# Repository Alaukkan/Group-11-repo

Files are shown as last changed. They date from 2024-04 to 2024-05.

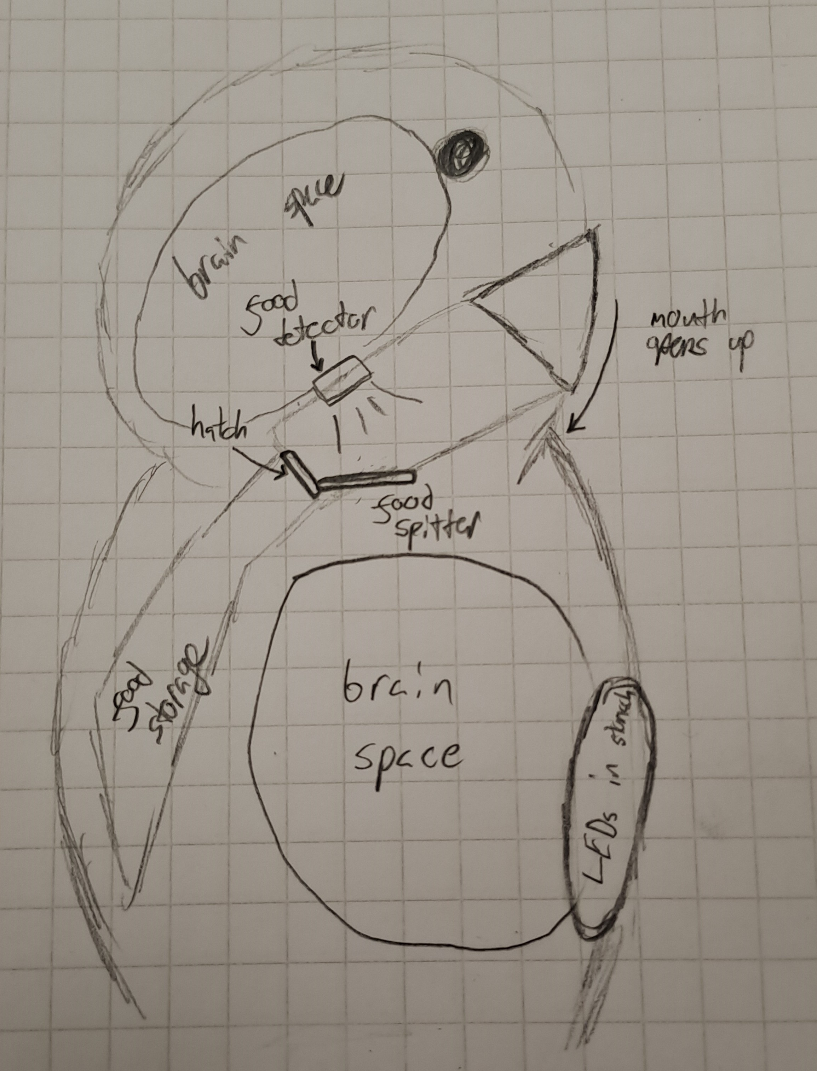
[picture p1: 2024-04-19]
Concept art/first-structure-sketch.jpg

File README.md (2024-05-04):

# Group-11 Repository

This is the repository for group-11's project in Principles of Digital Fabrication Course.

Members:
* Alex, programmer
* Anssi, prototyper
* Jouni, manager
* Petrus, designer

## Project Description

Aim of this project is to design and produce a desktop mounted robot pet resembling a penguin.
This robot pet, or RoboPet(™, Ⓒ, Patent Pending) if you will, will be stationary, but able to pivot in place and move its wings.
It is capable of simulating simple functions of a pet such as demanding particular food items and communicating using light, sound and motion.
Mechanical and structural parts needed for the project will be designed and 3D-printed by us.

## Contents of the Repository

In this repository you will find everything needed to copy and manufacture our project, including:

* Source code in main.py file.
* Additional modules, such as sound.py, servo.py, mfrc522.py, etc.
* .stl files containing design of the 3D-printed parts.
* .png and .fzz files containing schematics for electrical connections.
* .jpg and .png files containing concept art.
* Project RoboPet Documentation.md containing project description, parts list,
  software and tools used/needed, some code snippets highlighting key functionalities and information about the source code.
* README.md (this file you are reading) containing short project description,
  info about the contents of the repository and information about licenses.

## Licenses

##### The following legalese portion is not in effect yet.

Unless expressly stated otherwise all contend found in this specific repository (Alaukkan/Group-11-repo) is shared using [CC BY-SA license](https://creativecommons.org/share-your-work/cclicenses/).

More specifically above statement only relates to items used in completion of this project and those that are made by us (code or assets made by other people retain their original licenses and/or rights).

The above statements also don't extend to any other repositories made by user [Alaukkan](https://github.com/Alaukkan) or anyone else assosiated with the project or course.

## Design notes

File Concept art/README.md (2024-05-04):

# Concept art

## This folder contains images and schematics used in the project

## List of files

* alternate_first_design_of_final_concept.png
* first-structure-sketch.jpg
* initial_design_habitat.png
* main-idea.jpg

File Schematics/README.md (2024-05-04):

# Schematics

## This Folder contains .png and .fzz versions of the electronics schematics

## List of files:

* G11_Project_RoboPet_2.fzz
* G11_Project_Robopet_2.png

## Note that that Vcc for Pi Pico and Servos is provided by __Three__ (__3__) AA Batteries, not four (4)!

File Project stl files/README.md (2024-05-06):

# Project .stl files

## This folder contains .stl files that are used in the project

## List of files

* Axle_new.stl
* Battery_holder.stl
* Bottom_frame.stl
* Hat.stl
* Head.stl
* RFID_tag_42mm.stl
* Tongue.stl
* Torso.stl
* Wing.stl

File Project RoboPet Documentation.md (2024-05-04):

## Concept

Our product will be a (desktop) RoboPet (™, Ⓒ, Patent Pending), that is capable of simulating the most basic,
simple functions of a pet, namely the need for food and drink.
Product will be stationary and mounted on a rotating base, it will be able to turn left or right and move its arms
(other modes of movement might be implemented if there is time and/or resources).
Communication with the user will happen using coloured LEDs located in the torso and a buzzer located in the head.
For user interaction there will be an conveniently located on/off switch and a RFID-reader located in the mouth/head region.
RFID-reader is used to scan and recognize the different foodstuffs inserted.
A system for ingesting desired foodstuffs and discarding undesired ones will be implemented if there is time.

## Parts

* Raspberry Pi Pico W
* MFRC-522 RF-ID-Reader
* 5 RF-ID-Tags (13.56 MHz)
* 4 Servomotors (180 degree motion)
* 1 RGB LED
* Power Source (4.5V battery pack holding 3 AA batteries)
* 2 Breadboards
* Jumper Cables
* Resistors, capacitors
* 3D-Printed parts

## Tools and Software

* 3D-Printer (We used different versions of Ender-3)
* CAD Software (Fusion 360, FreeCAD, Blender with CAD Sketcher, etc.)
* Slicer Software (Cura, Slic3r, Simplify 3D, etc.)
* IDE (VS Code, Arduino IDE, Thonny, etc.)

## Functionality highlights

```Python
def read_tag():
    """
    Found library for rfid reader on github:
    https://github.com/danjperron/micropython-mfrc522
    Reads the RFID tag and returns which tag was read.
    """
    start_time = utime.time()
    reader.init()
    while utime.time() - start_time < 20:

        (stat, tag_type) = reader.request(reader.REQIDL)
        print('request stat:',stat,' tag_type:',tag_type)

        if stat == reader.OK:
            (stat, uid) = reader.SelectTagSN()
            if stat == reader.OK:
                tag_id = hex(int.from_bytes(bytes(uid),"little",False)).upper()
                print(f"{tag_to_color[tag_id]} tag detected")

                if tag_to_color[tag_id] == status["requesting_color"]:
                    return "correct"
                return "wrong"
            else:
                pass
        utime.sleep_ms(50)
    
    return "Timed out"

def output_color(color):
    """
    takes the rgb values from given parameter tuple and
    outputs the color to the RGB led
    """
    red = color[0]
    green = color[1]
    blue = color[2]
    rgb[0].duty_u16(round(65535 * red / 255))
    rgb[1].duty_u16(round(65535 * green / 255))
    rgb[2].duty_u16(round(65535 * blue / 255))

def request_food():
    """
    A random number is generated which decides what food item the Robo Pet
    wants by accessing the element in the led list. Robopet
    indicates what food it wants by a colored LED. 
    """
    random.seed(utime.time() - utime.time_ns())
    length = len(status["available"])
    if length > 1:
        item = random.randint(0, length - 1)
    else:
        item = 0
    status["requesting_color"] = status["available"][item]
    print(f"requesting food: {status["available"][item]}")
    output_color(rgb_colors[status["available"][item]])
    _thread.start_new_thread(sound.play_melody, ("requesting", 1))

def correct_food():
    """
    If the food is correct, led flashes white for 2 seconds
    both wings lift up
    hatch opens and closes
    """
    _thread.start_new_thread(sound.play_melody, ("happy", 1))
    servo_hatch.move(-60)
    servo_right_wing.move(-70)
    servo_left_wing.move(70)
    deinit_servos()
    for i in range(3):
        led_off()
        utime.sleep_ms(300)
        output_color(rgb_colors["white"])
        utime.sleep_ms(300)
    led_off()
    servo_hatch.move(0)
    servo_right_wing.move(0)
    servo_left_wing.move(0)
    deinit_servos()
    status["available"].remove(status["requesting_color"])
    status["requesting_color"] = "none"
    status["timed out"] = 0

def ending():
    if len(status["available"]) == 0:
        _thread.start_new_thread(sound.play_melody, ("victory", 1))
        for i in range(0, 255, 5):
            output_color((i, 0, 0))
            utime.sleep_ms(9)
        for i in range(0, 255, 5):
            output_color((255, i, 0))
            utime.sleep_ms(9)
        for i in range(0, 255, 5):
            output_color((255-i, 255, 0))
            utime.sleep_ms(9)
        for i in range(0, 255, 5):
            output_color((0, 255, i))
            utime.sleep_ms(9)
        for i in range(0, 255, 5):
            output_color((0, 255-i, 255))
            utime.sleep_ms(9)
        for i in range(0, 255, 5):
            output_color((i, 0, 255))
            utime.sleep_ms(9)
        for i in range(0, 255, 5):
            output_color((255, 0, 255-i))
            utime.sleep_ms(9)
    elif status["failed"] > 2:
        _thread.start_new_thread(sound.play_melody, ("defeat", 1))
        output_color(rgb_colors["red"])
        utime.sleep(1)
    elif status["timed out"] > 1:
        _thread.start_new_thread(sound.play_melody, ("power down", 1))
        for i in range(0, 255, 5):
            output_color((255, 255-i, 255-i))
            utime.sleep_ms(20)
    led_off()

```

## Source Code

Project is written and tested in [MicroPython](https://docs.micropython.org/en/latest/rp2/quickref.html) for RP2040 based
[Raspberry Pi Pico W](https://www.raspberrypi.com/documentation/microcontrollers/raspberry-pi-pico.html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),
functionality with other micro controllers is not tested.

Source Code can be found in the [GitHub repository](https://github.com/Alaukkan/Group-11-repo).

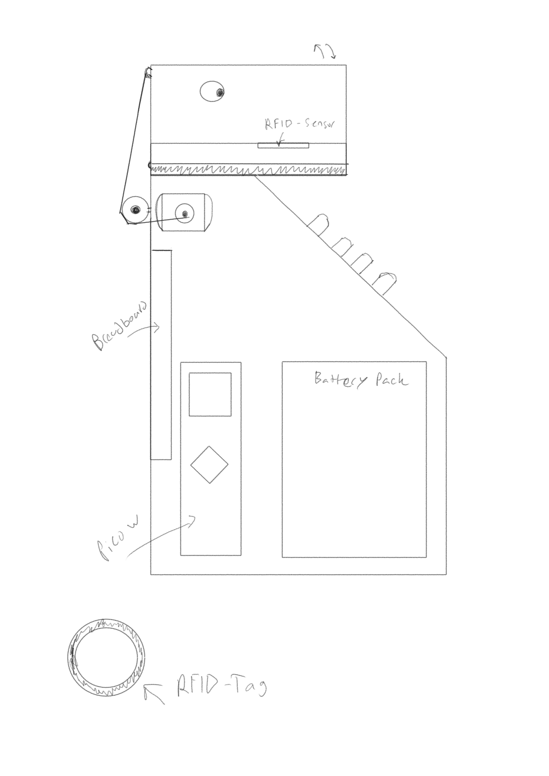
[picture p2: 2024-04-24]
Concept art/alternate_first_design_of_final_concept.png

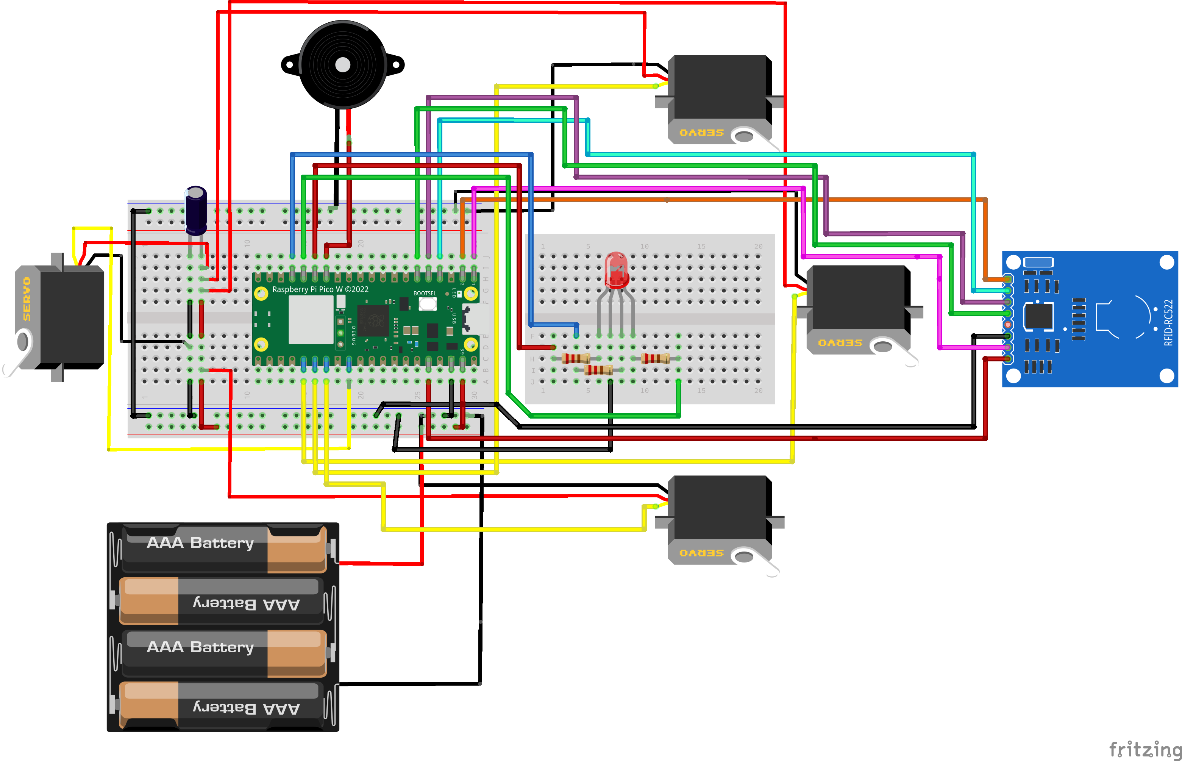
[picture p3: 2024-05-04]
Schematics/G11_Project_RoboPet_2.png

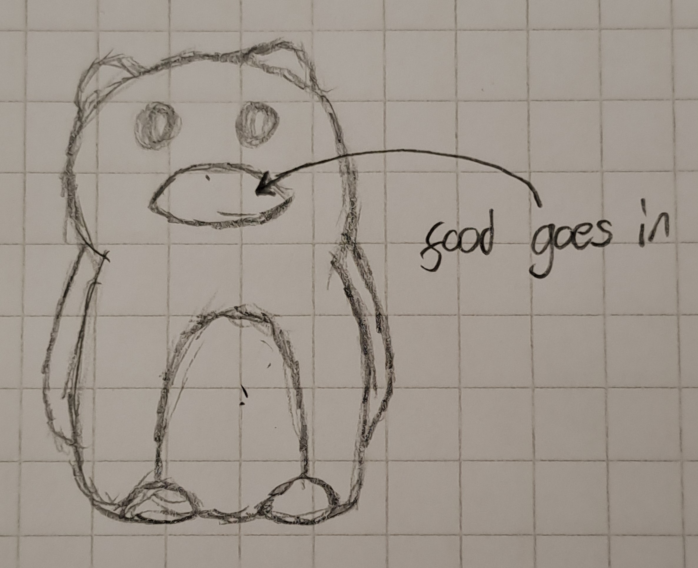
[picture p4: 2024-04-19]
Concept art/main-idea.jpg

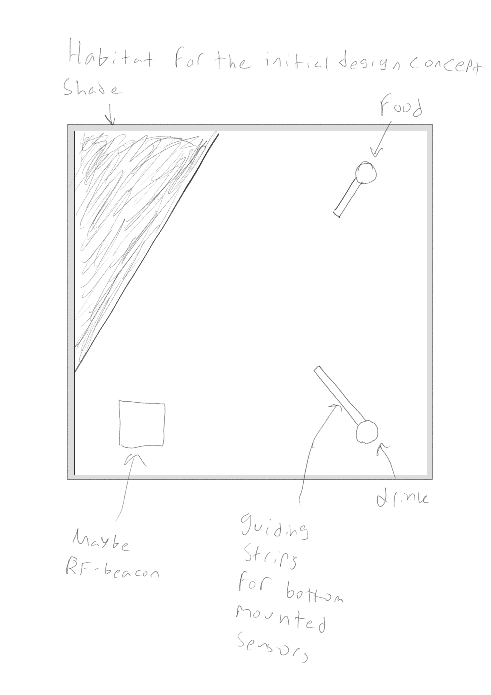
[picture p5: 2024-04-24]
Concept art/initial_design_habitat.png

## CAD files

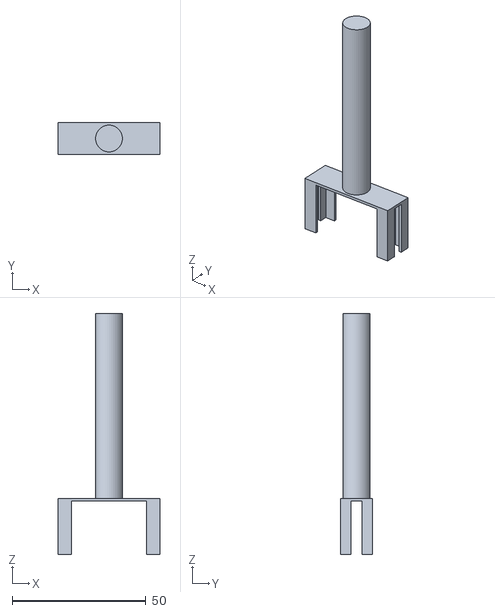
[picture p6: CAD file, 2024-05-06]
Project stl files/breadboard_holder_smaller.stl
38.0 x 12.0 x 90.0

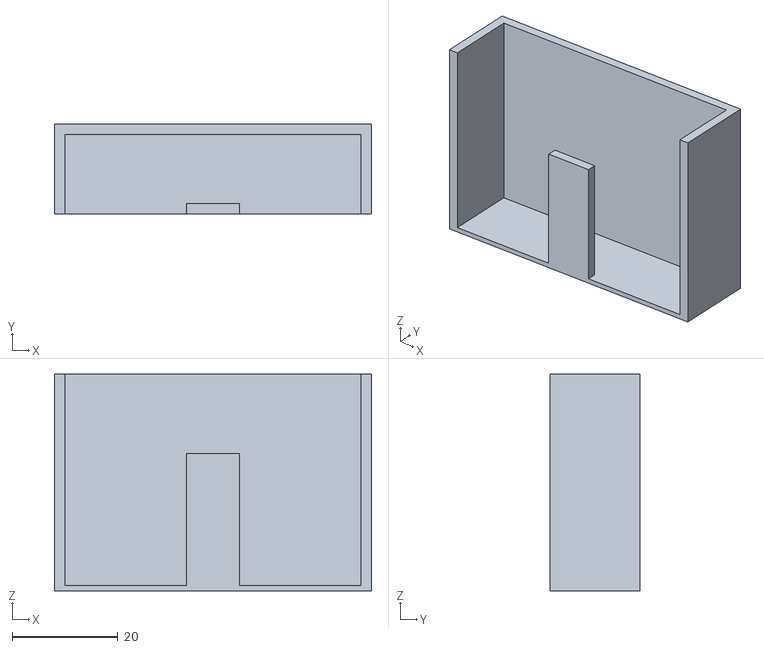
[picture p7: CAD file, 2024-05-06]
Project stl files/breadboard holder.stl
60.0 x 17.0 x 41.0

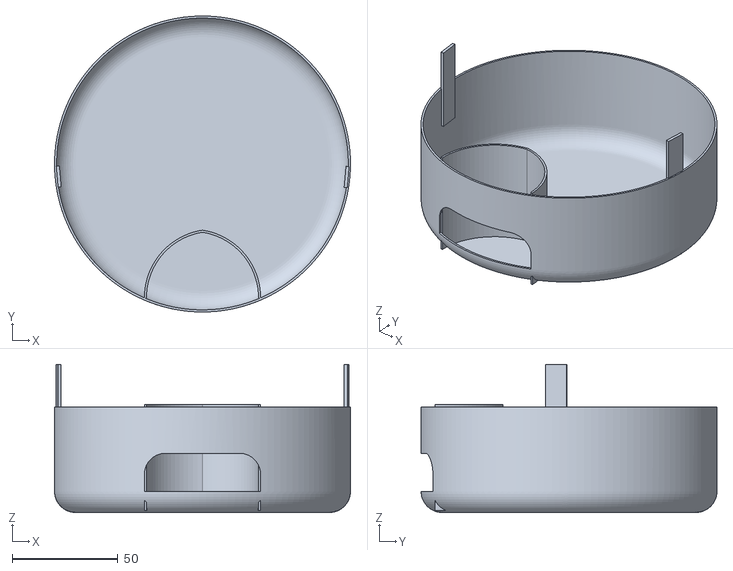
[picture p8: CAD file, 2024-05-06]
Project stl files/Bottom_of_torso.stl
140.0 x 140.0 x 70.0

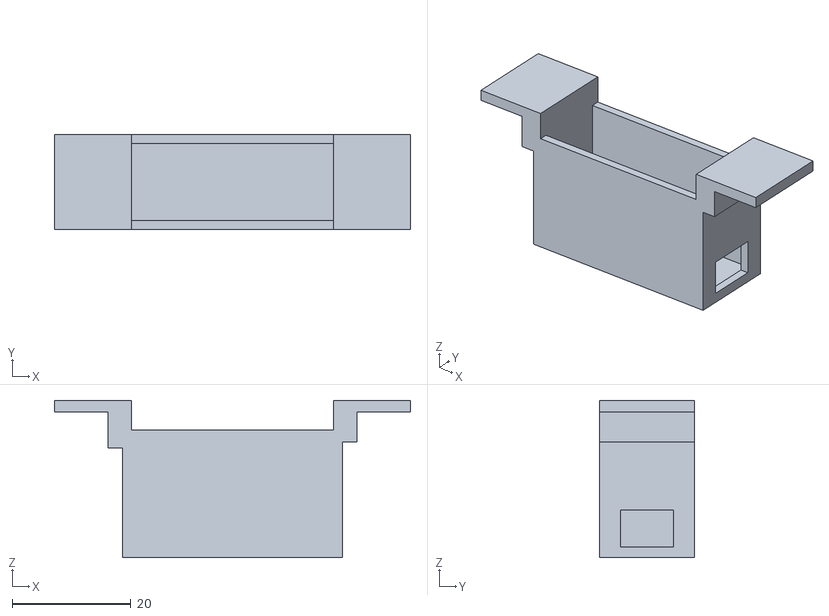
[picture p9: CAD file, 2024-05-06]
Project stl files/SERVO_HOLDER.stl
60.0 x 16.0 x 26.5

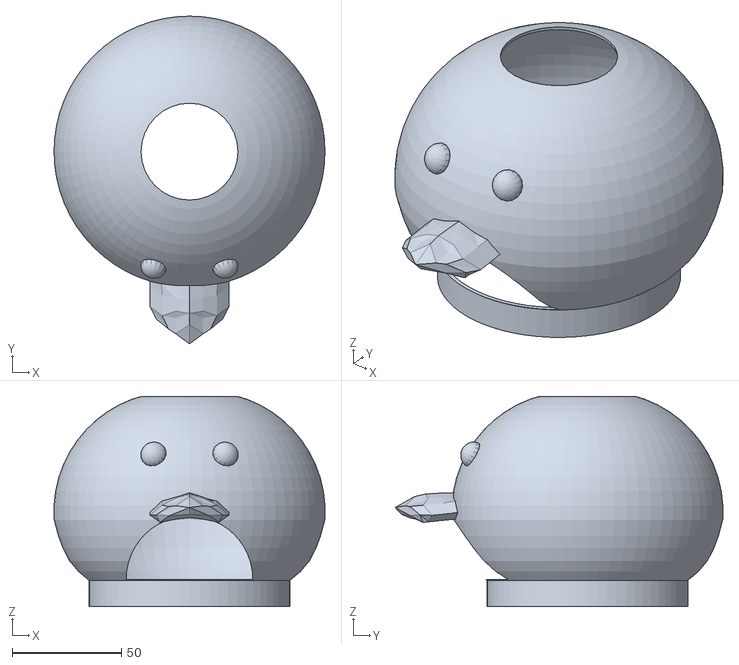
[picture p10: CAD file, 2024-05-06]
Project stl files/Head.stl
124.1 x 150.1 x 96.3

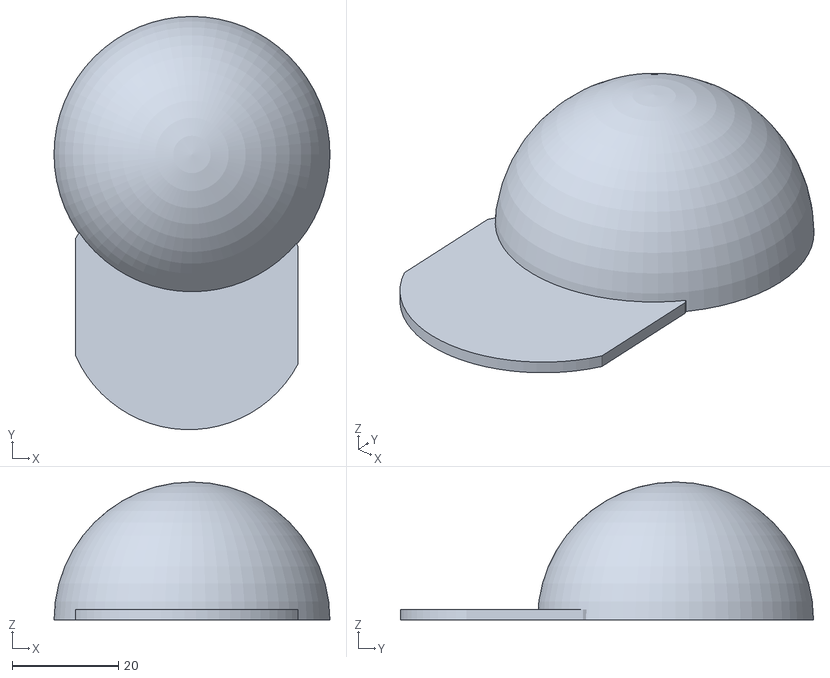
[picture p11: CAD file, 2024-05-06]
Project stl files/Hat.stl
52.0 x 77.8 x 26.0

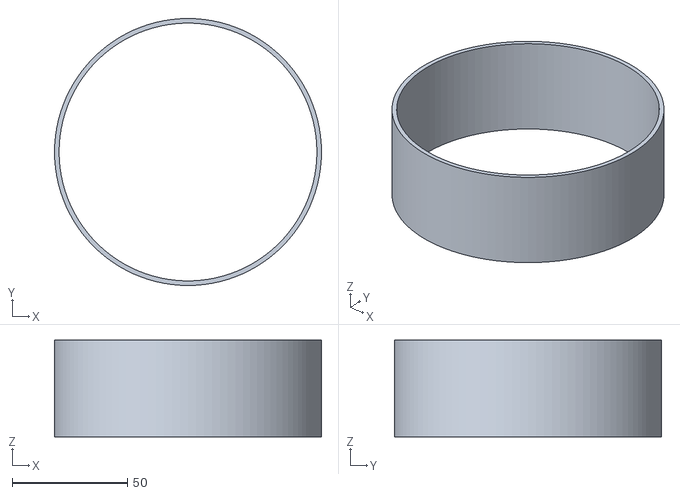
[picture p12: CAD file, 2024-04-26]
Project stl files/Bottom_frame.stl
116.0 x 116.0 x 42.0

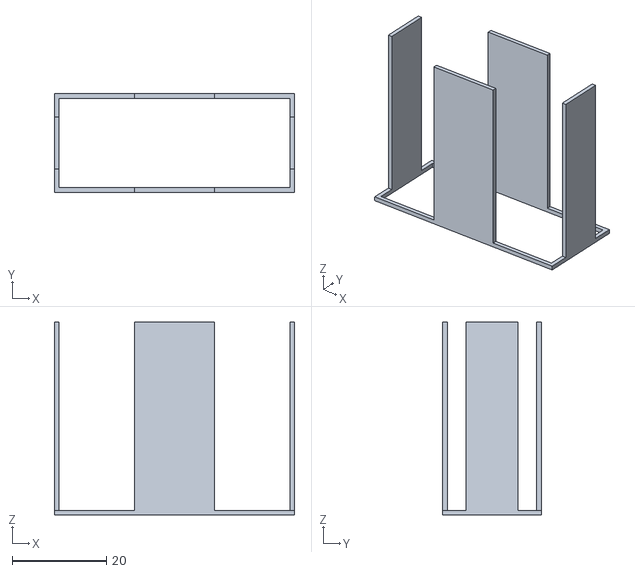
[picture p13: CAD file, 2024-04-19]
Project stl files/Battery_holder.stl
51.0 x 21.0 x 41.0

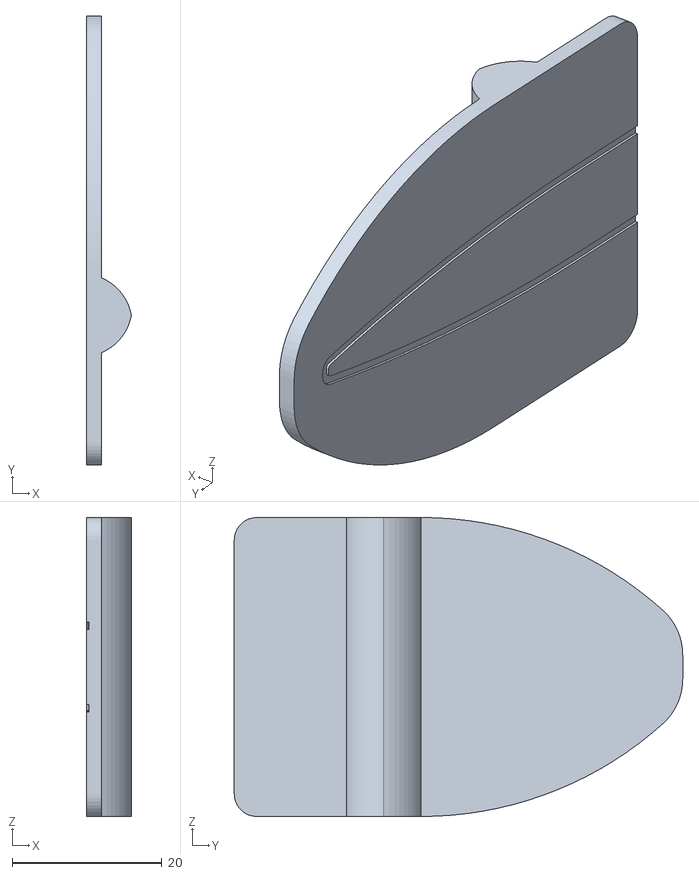
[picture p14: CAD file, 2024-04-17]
Project stl files/Tongue.stl
6.00 x 60.0 x 40.0

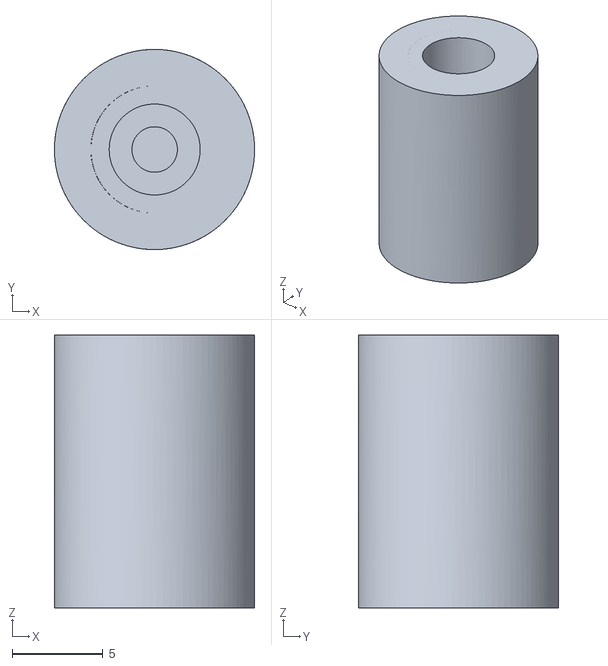
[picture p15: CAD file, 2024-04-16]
Project stl files/Axle_new.stl
11.0 x 11.0 x 15.0

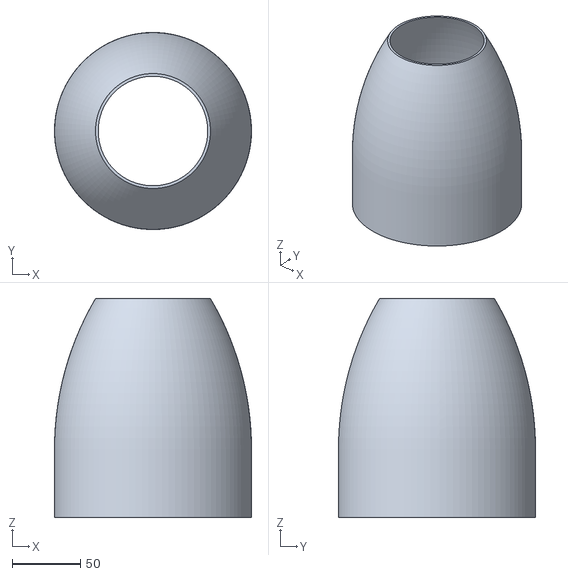
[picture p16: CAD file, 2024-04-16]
Project stl files/Torso.stl
144.0 x 144.0 x 160.0

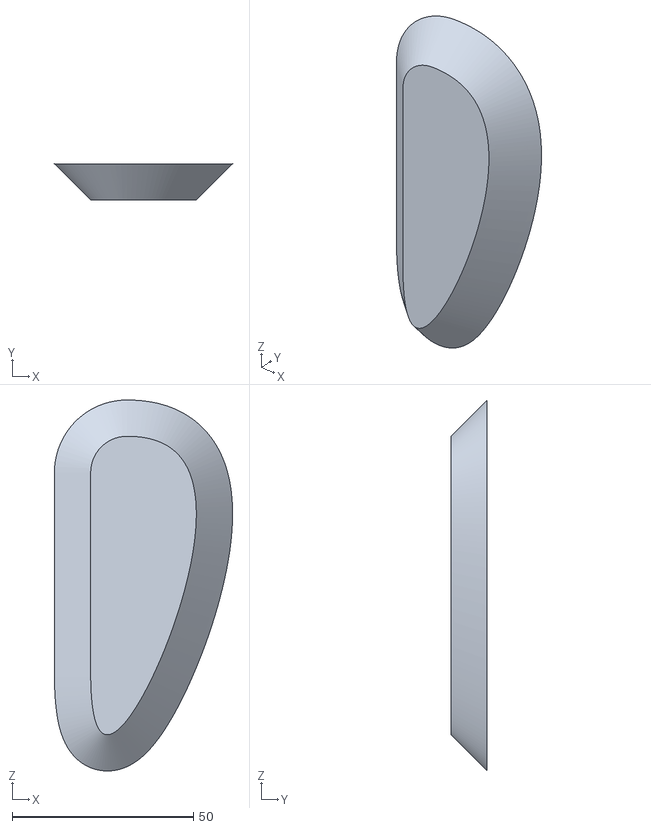
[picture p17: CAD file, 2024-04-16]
Project stl files/Wing.stl
49.1 x 10.0 x 102.3

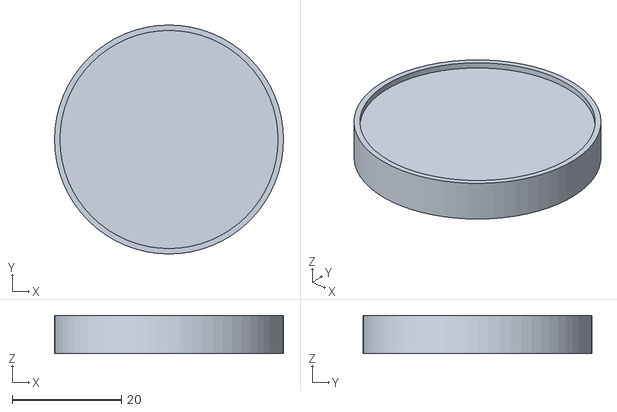
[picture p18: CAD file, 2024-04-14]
Project stl files/RFID_tag_42mm.stl
42.0 x 42.0 x 7.00

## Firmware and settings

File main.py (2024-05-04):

import random
import sound
import utime
import _thread
from machine import Pin, PWM
from mfrc522 import MFRC522
from servo import Servo

servo_hatch = Servo(19)
servo_right_wing = Servo(20)
servo_left_wing = Servo(21)
servo_rotator = Servo(22)

red_pin = PWM(Pin(11, Pin.OUT))
green_pin = PWM(Pin(12, Pin.OUT))
blue_pin = PWM(Pin(13, Pin.OUT))
red_pin.freq(1000)
green_pin.freq(1000)
blue_pin.freq(1000)

rgb = [red_pin, green_pin, blue_pin]
rgb_colors = {
    "red" : (255, 0, 0),
    "green" : (0, 255, 0),
    "blue" : (0, 0, 255),
    "yellow" : (255, 170, 0),
    "purple" : (200, 0, 255),
    "white" : (255, 255, 255)
}
                # pin numbers for RFID reader
reader = MFRC522(spi_id=0,sck=2,miso=4,mosi=3,cs=1,rst=0)
tag_to_color = {
    "0X8020B7B21B4404" : "red",
    "0X8020B7B21B6304" : "green",
    "0X8020B7B21B5504" : "blue",
    "0X8020B7B21B4304" : "yellow",
    "0X8020B7B21A8704" : "purple"
}

status = {
    "available" : ["red", "green", "blue", "yellow", "purple"],
    "requesting_color" : "none",
    "failed" : 0,
    "timed out" : 0
}

def output_color(color):
    """
    takes the rgb values from given parameter tuple and
    outputs the color to the RGB led
    """
    red = color[0]
    green = color[1]
    blue = color[2]
    rgb[0].duty_u16(round(65535 * red / 255))
    rgb[1].duty_u16(round(65535 * green / 255))
    rgb[2].duty_u16(round(65535 * blue / 255))

def led_off():
    """Turns off the RGB led"""
    rgb[0].duty_u16(0)
    rgb[1].duty_u16(0)
    rgb[2].duty_u16(0)

def deinit_servos():
    """ 
    Deinitialises servos to prevent jittering when idle
    """
    utime.sleep_ms(500)
    servo_hatch.__motor.deinit()
    servo_left_wing.__motor.deinit()
    servo_right_wing.__motor.deinit()
    servo_rotator.__motor.deinit()

def request_food():
    """
    A random number is generated which decides what food item the Robo Pet
    wants by accessing the element in the led list. Robopet
    indicates what food it wants by a colored LED. 
    """
    random.seed(utime.time() - utime.time_ns())
    length = len(status["available"])
    if length > 1:
        item = random.randint(0, length - 1)
    else:
        item = 0
    status["requesting_color"] = status["available"][item]
    print(f"requesting food: {status["available"][item]}")
    output_color(rgb_colors[status["available"][item]])
    _thread.start_new_thread(sound.play_melody, ("requesting", 1))

def read_tag():
    """
    Found library for rfid reader on github:
    https://github.com/danjperron/micropython-mfrc522
    Reads the RFID tag and returns which tag was read.
    """
    start_time = utime.time()
    reader.init()
    while utime.time() - start_time < 20:

        (stat, tag_type) = reader.request(reader.REQIDL)
        print('request stat:',stat,' tag_type:',tag_type)

        if stat == reader.OK:
            (stat, uid) = reader.SelectTagSN()
            if stat == reader.OK:
                tag_id = hex(int.from_bytes(bytes(uid),"little",False)).upper()
                print(f"{tag_to_color[tag_id]} tag detected")

                if tag_to_color[tag_id] == status["requesting_color"]:
                    return "correct"
                return "wrong"
            else:
                pass
        utime.sleep_ms(50)
    
    return "Timed out"

def correct_food():
    """
    If the food is correct, led flashes white for 2 seconds
    both wings lift up
    hatch opens and closes
    """
    _thread.start_new_thread(sound.play_melody, ("happy", 1))
    servo_hatch.move(-60)
    servo_right_wing.move(-70)
    servo_left_wing.move(70)
    deinit_servos()
    for i in range(3):
        led_off()
        utime.sleep_ms(300)
        output_color(rgb_colors["white"])
        utime.sleep_ms(300)
    led_off()
    servo_hatch.move(0)
    servo_right_wing.move(0)
    servo_left_wing.move(0)
    deinit_servos()
    status["available"].remove(status["requesting_color"])
    status["requesting_color"] = "none"
    status["timed out"] = 0

def wrong_food():
    """
    If the Robo Pet is given the wrong food, 
    the requested led will flash for 2 seconds and will stay on
    robopet rotates left and right
    wings move simultaniously opposite directions
    hatch opens "spitting" the food out and closes
    """
    _thread.start_new_thread(sound.play_melody, ("angry", 1))
    servo_hatch.move(30)
    deinit_servos()
    for i in range(3):
        led_off()
        for i in range(30):
            servo_right_wing.move(-1.5 * i)
            servo_left_wing.move(-1.5 * i)
            servo_rotator.move(i)
            utime.sleep_ms(10)
        output_color(rgb_colors[status["requesting_color"]])
        for i in range(60):
            servo_right_wing.move(-1.5 * (30 - i))
            servo_left_wing.move(-1.5 * (30 - i))
            servo_rotator.move(30 - i)
            utime.sleep_ms(10)
        for i in range(30):
            servo_right_wing.move(1.5 * (30 - i))
            servo_left_wing.move(1.5 * (30 - i))
            servo_rotator.move(i - 30)
            utime.sleep_ms(10)
    servo_right_wing.move(0)
    servo_left_wing.move(0)
    servo_hatch.move(0)
    servo_rotator.move(0)
    deinit_servos()
    status["failed"] += 1
    status["timed out"] = 0

def timed_out():
    """
    If the Robo Pet times out, the led does a long white flash
    hatch opens and closes (spits food out)
    """
    _thread.start_new_thread(sound.play_melody, ("timed out", 1))
    servo_hatch.move(30)
    deinit_servos()
    output_color(rgb_colors["white"])
    utime.sleep(2)
    led_off()
    utime.sleep(1)
    servo_hatch.move(0)
    deinit_servos()
    status["requesting_color"] = "none"
    status["timed out"] += 1

def ending():
    if len(status["available"]) == 0:
        _thread.start_new_thread(sound.play_melody, ("victory", 1))
        for i in range(0, 255, 5):
            output_color((i, 0, 0))
            utime.sleep_ms(9)
        for i in range(0, 255, 5):
            output_color((255, i, 0))
            utime.sleep_ms(9)
        for i in range(0, 255, 5):
            output_color((255-i, 255, 0))
            utime.sleep_ms(9)
        for i in range(0, 255, 5):
            output_color((0, 255, i))
            utime.sleep_ms(9)
        for i in range(0, 255, 5):
            output_color((0, 255-i, 255))
            utime.sleep_ms(9)
        for i in range(0, 255, 5):
            output_color((i, 0, 255))
            utime.sleep_ms(9)
        for i in range(0, 255, 5):
            output_color((255, 0, 255-i))
            utime.sleep_ms(9)
    elif status["failed"] > 2:
        _thread.start_new_thread(sound.play_melody, ("defeat", 1))
        output_color(rgb_colors["red"])
        utime.sleep(1)
    elif status["timed out"] > 1:
        _thread.start_new_thread(sound.play_melody, ("power down", 1))
        for i in range(0, 255, 5):
            output_color((255, 255-i, 255-i))
            utime.sleep_ms(20)
    led_off()

def timer(min, max):
    """
    Delays the excecution of the code by a random amount of time.
    min = shortest possible delay
    max = longest possible delay
    """
    delay = random.randint(min, max)
    print(f"timer: {delay}")
    utime.sleep(delay)

def check_state():
    """
    Checks the game state. Returns false if:
    - all rfid tags have been read
    - 3 wrong rfid tags have been read
    - timed out 2 times in a row
    """
    return len(status["available"]) > 0 and status["failed"] < 3 and status["timed out"] < 2

def main():
    """
    The main function of the pet. Based on the timer the pet will get hungry
    and demand food. 
    """
    deinit_servos()
    while check_state():
        timer(2, 5)
        request_food()
        while check_state():
            result = read_tag()
            if result == "wrong":
                wrong_food()
            elif result == "correct":
                correct_food()
                break
            else:
                timed_out()
                break
    ending()

main()

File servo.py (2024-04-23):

# Basic servo library found here:
# https://forums.raspberrypi.com/viewtopic.php?t=303900

from machine import Pin, PWM

class Servo:
    # these defaults work for the standard TowerPro SG90
    __servo_pwm_freq = 50
    __min_u16_duty = 1640 + 400 # offset for correction
    __max_u16_duty = 7864 - 35  # offset for correction
    min_angle = -90
    max_angle = 90    
    current_angle = 0.001
    
    
    def __init__(self, pin):
        self.__initialise(pin)
        
        
    def update_settings(self, servo_pwm_freq, min_u16_duty, max_u16_duty, min_angle, max_angle, pin):
        self.__servo_pwm_freq = servo_pwm_freq
        self.__min_u16_duty = min_u16_duty
        self.__max_u16_duty = max_u16_duty
        self.min_angle = min_angle
        self.max_angle = max_angle
        self.__initialise(pin)
        
        
    def move(self, angle):
        # round to 2 decimal places, so we have a chance of reducing unwanted servo adjustments
        angle = round(angle, 2)
        # do we need to move?
        if angle == self.current_angle:
            return
        self.current_angle = angle
        # calculate the new duty cycle and move the motor
        duty_u16 = self.__angle_to_u16_duty(angle)        
        self.__motor.duty_u16(duty_u16)

        
        
    def __angle_to_u16_duty(self, angle):
        return int((angle - self.min_angle) * self.__angle_conversion_factor) + self.__min_u16_duty
    
    
    def __initialise(self, pin):
        self.current_angle = -0.001
        self.__angle_conversion_factor = (self.__max_u16_duty - self.__min_u16_duty) / (self.max_angle - self.min_angle)
        self.__motor = PWM(Pin(pin))
        self.__motor.freq(self.__servo_pwm_freq)

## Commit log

2024-04-05 Prototype with buttons simulating the RFID chips
2024-04-10 Made directory for button prototypes and added a new version with an RGB led
2024-04-14 Create README.md for project stl files folder
2024-04-14 Uploaded a version of RFID-Tag
    [RFID_Tag_2x21mm.stl]
2024-04-15 Added a prototype design made from memory
    Don't print without checking the measurements.
    [Servo_to_Axle_Mount_v0.stl]
2024-04-16 Prototype for the tongue
    [Tongue_v3.stl]
2024-04-16 Add files via upload
    a prototype for the wings
    [Siipi1.stl]
2024-04-16 wing
    Prototype for the wings
    [wing.stl]
2024-04-16 Upper torso
    [Torso.stl]
2024-04-16 a prototype of the torso
    [torso.stl]
2024-04-17 Final prototype of tongue
    [Tongue_3 v3.stl]
2024-04-19 Battery holder
    [kehikko_paristoille v3.stl]
2024-04-24 Create README.md for Schematics folder
2024-04-26 frame to the bottom
    [Kehikko_pohjalle.stl]
2024-05-04 Breadboard view of electrical connections
    [G11_Project_RoboPet_2.fzz]
2024-05-06 A hat for the RoboPet
    Remember to scale to desired size before printing.
    [a_hat1.stl]
2024-05-06 Head for RoboPet
    [Neue_haupt10.stl]
2024-05-06 Rename kehikko_paristoille v3.stl to Battery_holder.stl
    [Battery_holder.stl]
2024-05-06 Holders for the servos to the wings
    [SERVO_HOLDER.stl]
2024-05-06 The bottom part of the torso with RFID tag storage
    [Bottom_of_torso.stl]
2024-05-06 Holder for the bigger breadboard
    [breadboard holder.stl]
2024-05-06 Holder for the smaller breadboard with a stand
    [breadboard_holder_smaller.stl]
